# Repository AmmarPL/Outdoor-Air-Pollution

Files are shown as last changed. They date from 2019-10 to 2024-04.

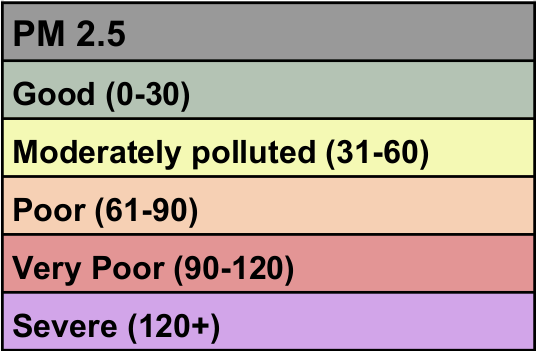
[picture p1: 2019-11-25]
Presentation/Inverse_Distance_Plots/Final/pm2.5.png

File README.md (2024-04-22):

# Embedded System for Air Quality Measurement

This project involves the design and implementation of an embedded system to measure air quality, with a focus on particulate matter (PM10) concentrations. It was specifically developed and tested during Diwali in 2019, when air pollution levels are known to spike significantly due to fireworks and other festivities.

# Overview
The air quality measurement device uses an ESP8266 microcontroller to gather data from various sensors and transmit it to a Python Flask server using oneM2M. The data is then visualized and analyzed through Thingspeak, showcasing significant spikes in PM10 levels, particularly around student residential areas. The entire circuit was designed using EagleCAD.

# Features
Sensor Integration: Incorporates multiple sensors to measure various pollutants, with a focus on PM10 particulate matter.

Connectivity: Uses an ESP8266 microcontroller for processing sensor data and providing Wi-Fi connectivity.


Data Handling: Transmits data to a Python Flask server, which is then pushed to Thingspeak for analysis and visualization.


EagleCAD Design: Custom PCB design for neatly organized and efficient sensor integration and microcontroller setup.


# Results
We found that some of the air quality indicators had a bad spike around Diwali.



We also found that these spikes were concentrated around the student residences. 



Both these plots are for PM10, but similar spikes were found in PM2.5 and CO, but not with NH3 and NO2.

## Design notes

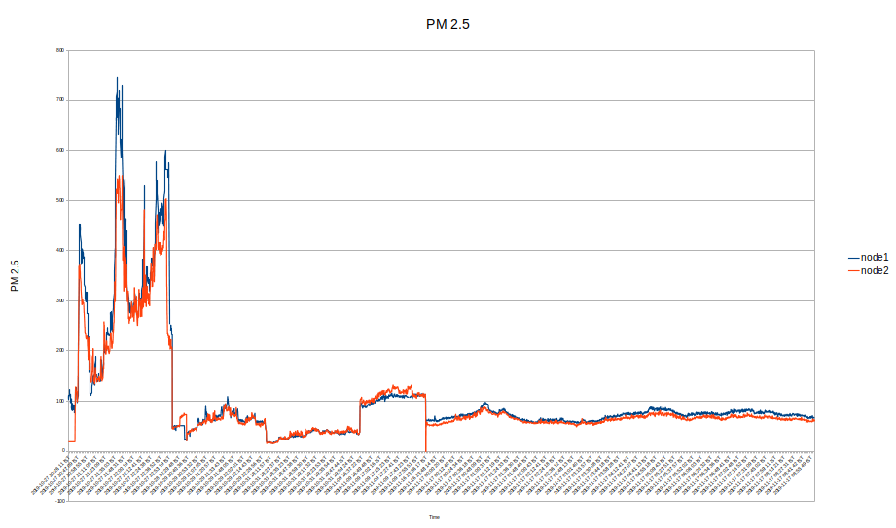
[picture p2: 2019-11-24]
Presentation/Node_Comparison/PM25_1_2.png

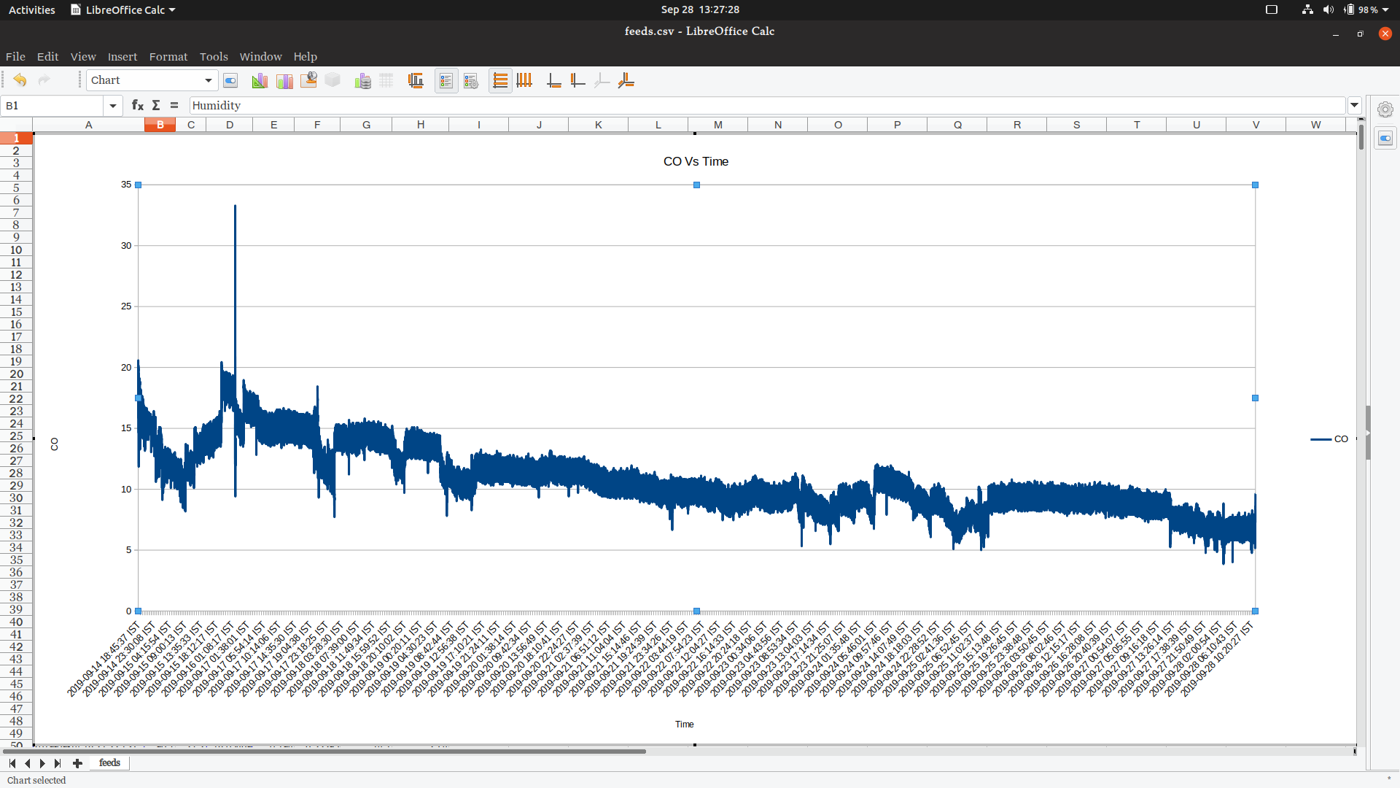
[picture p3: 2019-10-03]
Presentation/Team6_Plots/CO.png

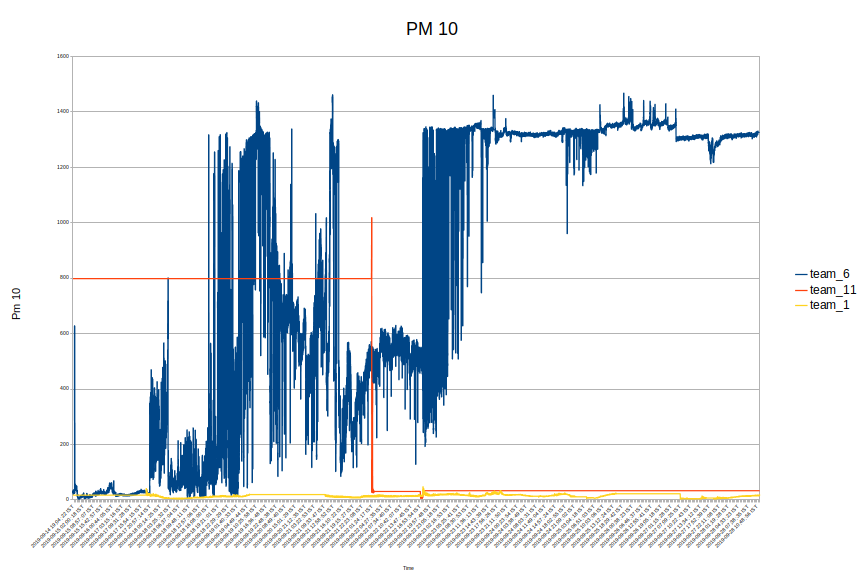
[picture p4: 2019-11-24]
Presentation/Comparison_Plots/Pm10.png

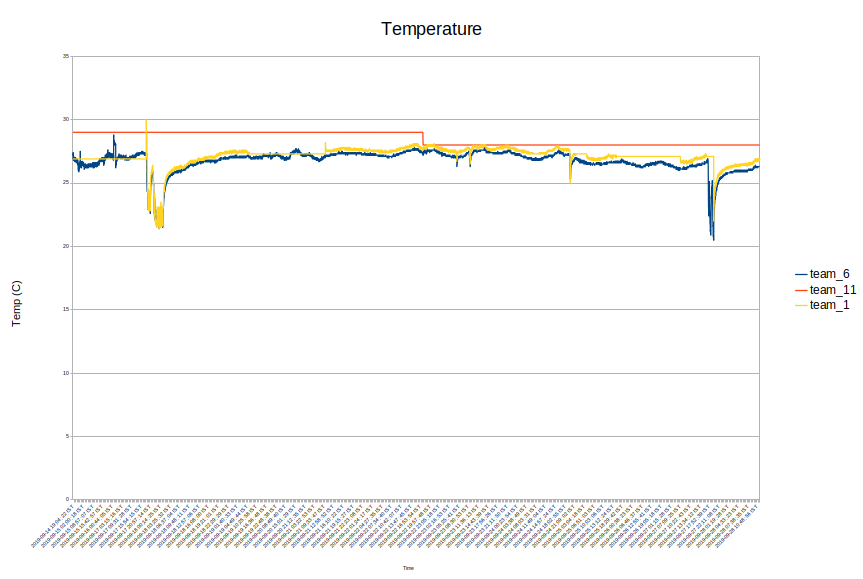
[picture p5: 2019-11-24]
Presentation/Comparison_Plots/Temperature.png

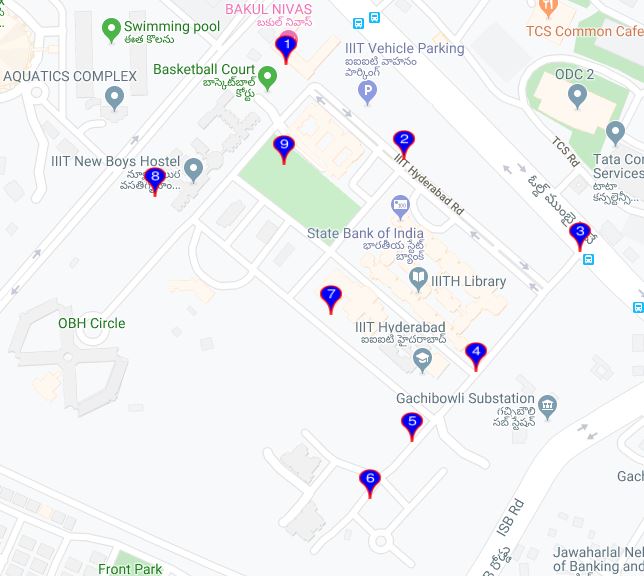
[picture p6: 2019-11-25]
Presentation/Locations/Map (2).JPG

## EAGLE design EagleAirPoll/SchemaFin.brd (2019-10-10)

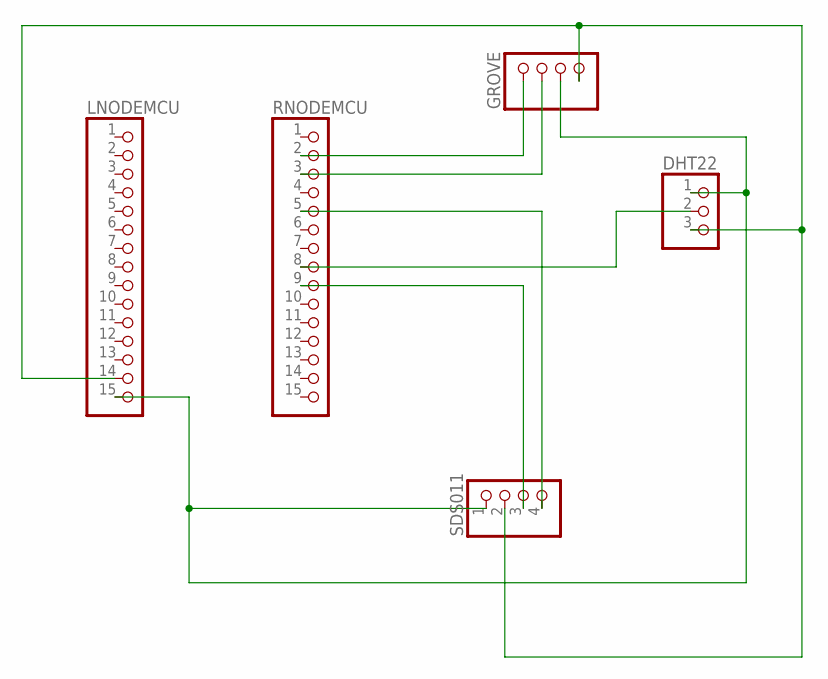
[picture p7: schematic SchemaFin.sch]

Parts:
DHT22: PINHD-1X3; 1X03
GROVE: PINHD-1X4M; 1X04M
LNODEMCU: PINHD-1X15; 1X15
RNODEMCU: PINHD-1X15; 1X15
SDS011: PINHD-1X4; 1X04

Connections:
unnamed: GROVE.1, RNODEMCU.2
unnamed: GROVE.2, RNODEMCU.3
unnamed: RNODEMCU.5, SDS011.4
unnamed: DHT22.2, RNODEMCU.8
unnamed: RNODEMCU.9, SDS011.3
unnamed: DHT22.1, GROVE.3, LNODEMCU.15, SDS011.1
unnamed: DHT22.3, GROVE.4, LNODEMCU.14, SDS011.2

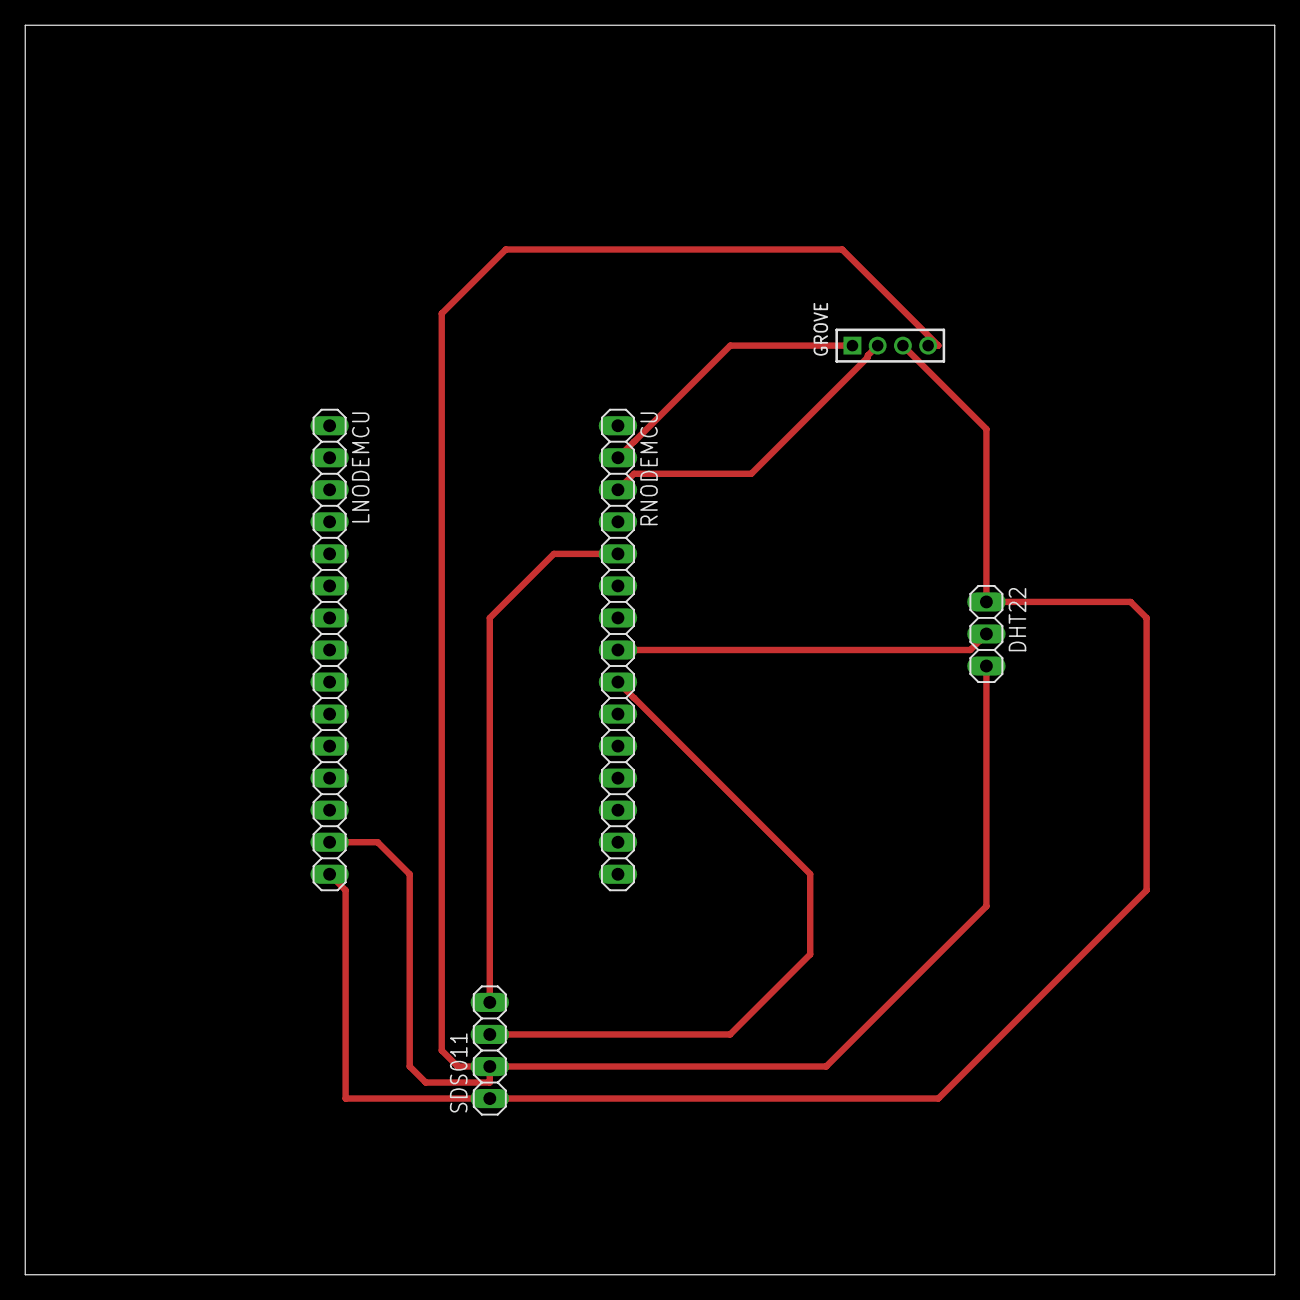
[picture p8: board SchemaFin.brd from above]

Board: 2 copper layers, 99.1 x 99.1 mm, 5 parts (0 on the bottom side), 7 nets.

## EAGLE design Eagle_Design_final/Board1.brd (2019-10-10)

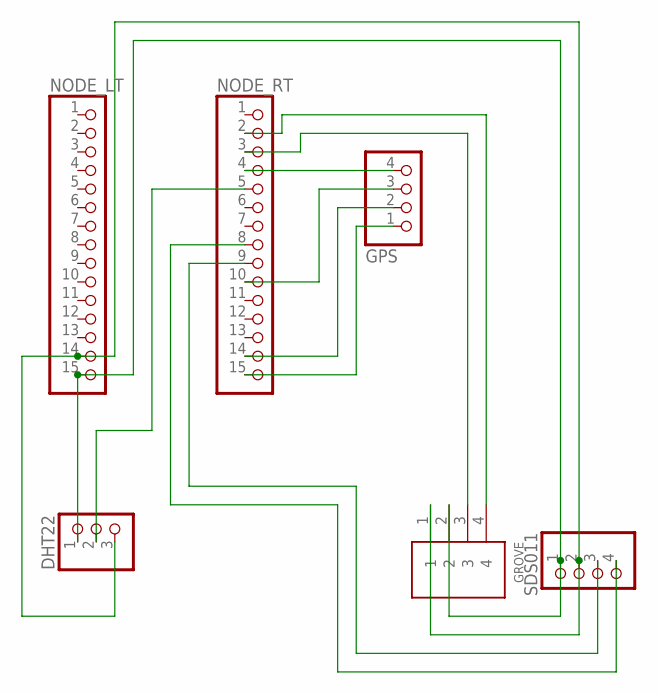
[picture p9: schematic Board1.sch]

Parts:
DHT22: PINHD-1X3; 1X03
GPS: PINHD-1X4; 1X04
GROVE: 4PIN; B4B-PH-K-S
NODE_LT: PINHD-1X15; 1X15
NODE_RT: PINHD-1X15; 1X15
SDS011: PINHD-1X4; 1X04

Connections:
unnamed: DHT22.1, GROVE.2, NODE_LT.15, SDS011.1
unnamed: DHT22.3, GROVE.1, NODE_LT.14, SDS011.2
unnamed: GPS.4, NODE_RT.4
unnamed: GPS.3, NODE_RT.10
unnamed: DHT22.2, NODE_RT.5
unnamed: NODE_RT.9, SDS011.3
unnamed: GPS.2, NODE_RT.14
unnamed: GROVE.3, NODE_RT.3
unnamed: GROVE.4, NODE_RT.2
unnamed: GPS.1, NODE_RT.15
unnamed: NODE_RT.8, SDS011.4

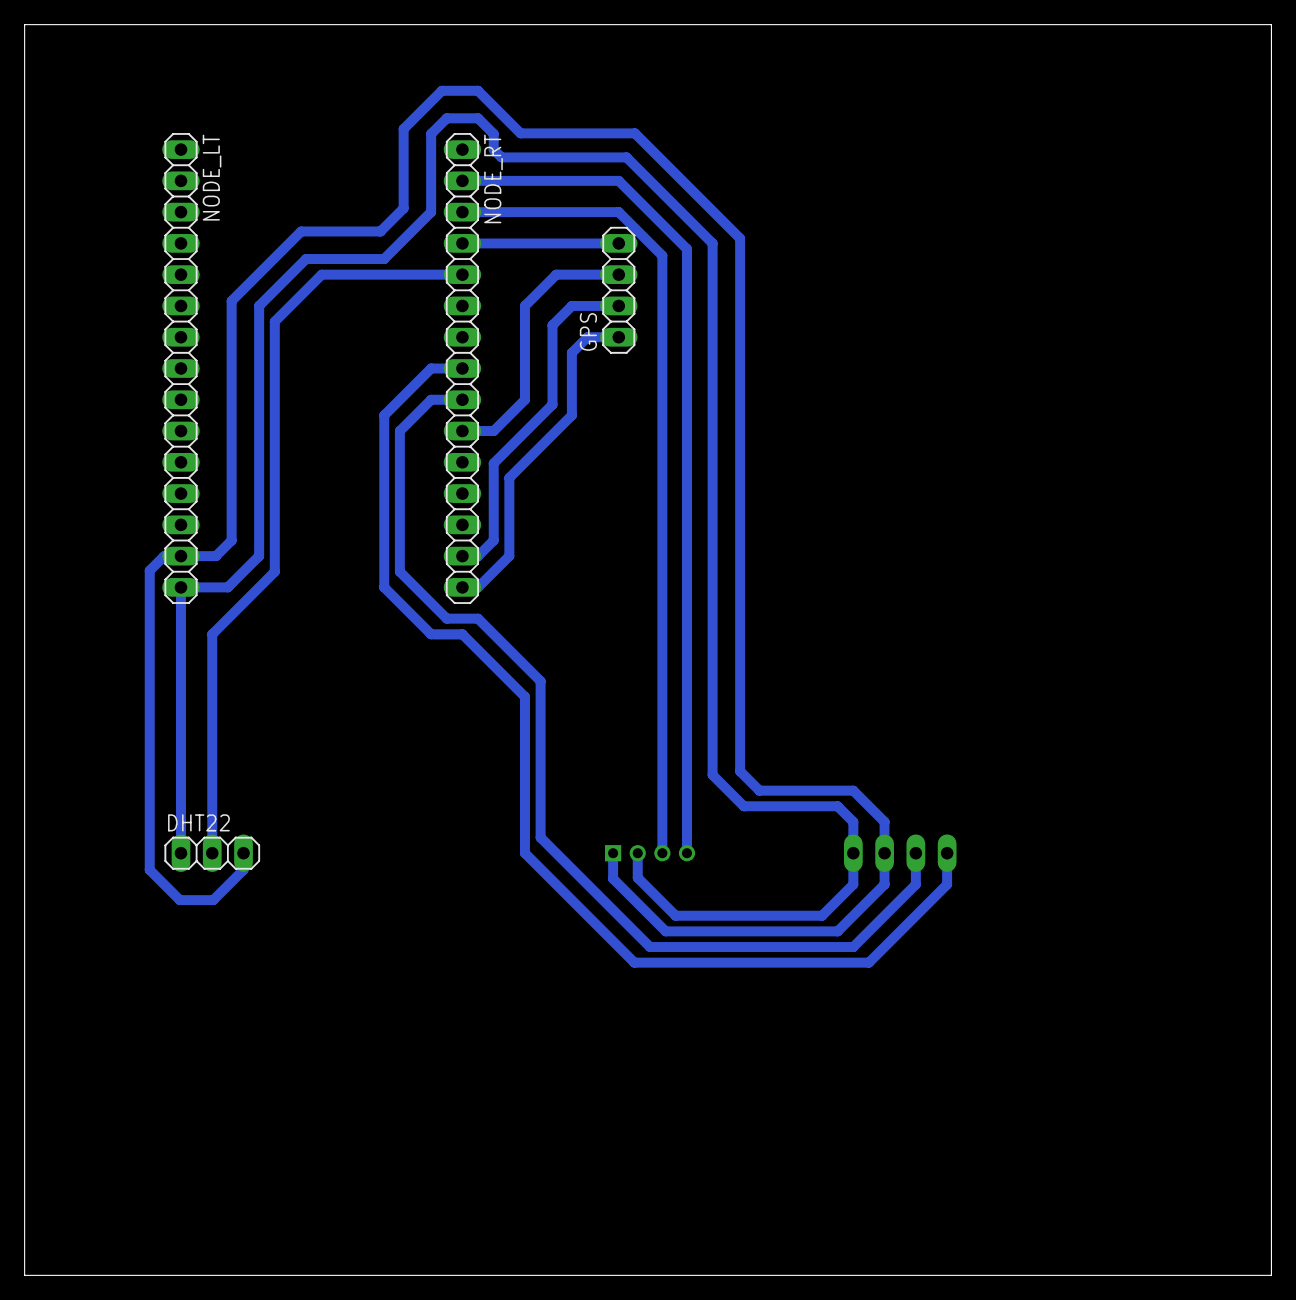
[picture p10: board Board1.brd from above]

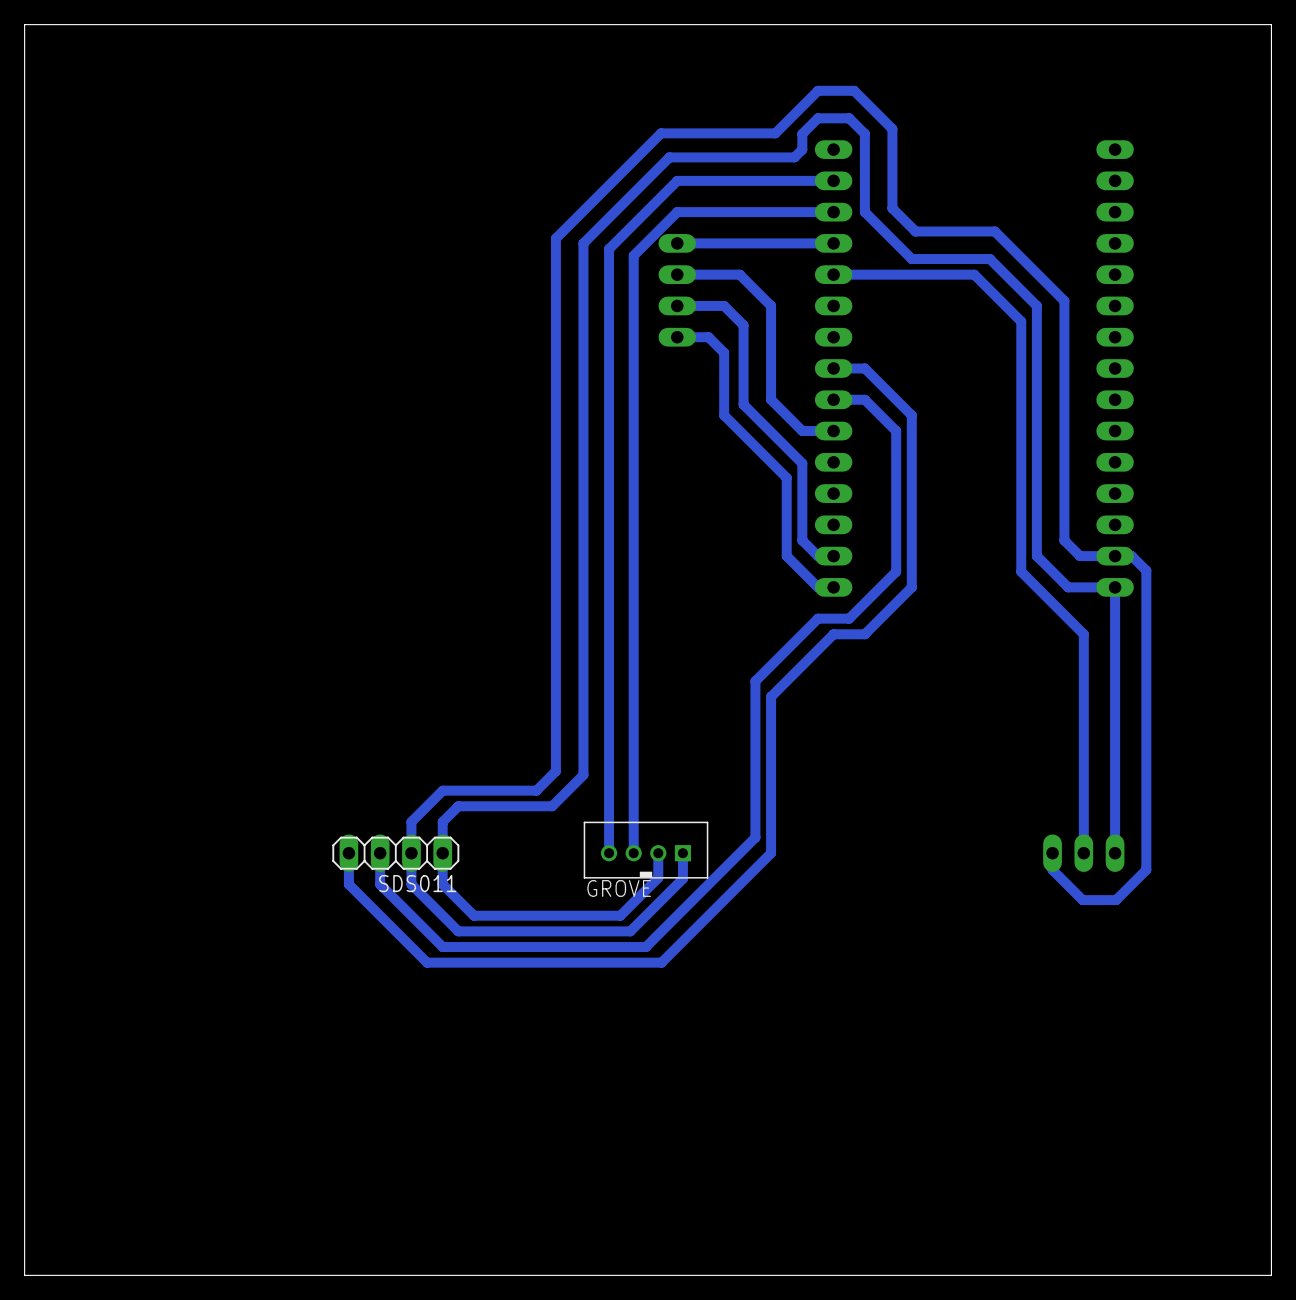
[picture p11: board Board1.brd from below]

Board: 2 copper layers, 101.3 x 101.6 mm, 6 parts (2 on the bottom side), 11 nets.

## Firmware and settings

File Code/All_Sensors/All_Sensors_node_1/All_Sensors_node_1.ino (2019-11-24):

//Libraries
#include <ThingSpeak.h>
#include "ESP8266WiFi.h"
#include "DHT.h"
#include <Wire.h>
#include "MutichannelGasSensor.h"
#include <SDS011.h>
#include <ESP8266HTTPClient.h>
#include <stdlib.h>
#include <SoftwareSerial.h>
#include <TinyGPS.h>


//Constants
#define DHTPIN D4    // what pin we're connected to
#define DHTTYPE DHT22   // DHT 22  (AM2302)
#define node_RX D5
#define node_TX D6
#define ADDR_I2C 0x04
#define LED D0
#define gps_RX D7
#define gps_TX D3
TinyGPS gps;
SoftwareSerial ss(gps_TX, gps_RX);
SDS011 my_sds;
DHT dht(DHTPIN, DHTTYPE); // Initialize DHT sensor for normal 16mhz Arduino
unsigned long Channel_ID = 864148;
char API_KEY[] = "UKQQPFB6U0R8V4US";
//char ssid[] = "JioFi_20E7D6C";
//char psswd[] = "2wufpbqmx0";
//char ssid[] = "esw-m19@iiith";
//char psswd[] = "e5W-eMai@3!20hOct";
//char ssid[] = "Nitro 5";
//char psswd[] = "wvZu69eF";
char ssid[] = "MGG5";
char psswd[] = "drowssapp";
WiFiClient  client;

//Variables
int chk, error;
float hum, temp, p10, p25, c, flat, flon;
String data;
unsigned long age;

//ONEM2M
int post(String ae, String container, String data) {
  String server = "http://onem2m.iiit.ac.in:80";
  String cse = "/~/in-cse/in-name/";
  char m2m[200];
  String Data;
  Data = "{\"m2m:cin\": {"
    "\"con\":\"" + data + "\""
    "}}";
  HTTPClient http;
  Serial.println("\nConnecting to : " + server+cse+ae+container);
  if(http.begin(server+cse+ae+container)) {
    http.addHeader("X-M2M-Origin", "admin:admin");
    http.addHeader("Content-type", "application/json;ty=4");
    Serial.println("Uploading data: " + data);
    int response = http.POST(Data);
    http.end();
    return response;
  }
  else {
    return 1;
  }
}

void update(int val) {
  if(val == 201) Serial.println("Data updated to OneM2M successfully\n");
  else Serial.println("There was an error while uploading Data to OneM2M. Error Code: " + String(val));
}

static void smartdelay(unsigned long ms) {
  unsigned long start = millis();
  do {
    while (ss.available())
      gps.encode(ss.read());
  } while (millis() - start < ms);
}

static void print_float(float val, float invalid, int len, int prec, int md) {
  char *temp;
  if (val == invalid) {
    while (len-- > 1){
      Serial.print('*');
      data = data + '*';
    }
    Serial.print(' ');
  }
  else{
    char temp[50];
    sprintf(temp, "%.6f", val);
    Serial.print(val, prec);
    data = data + String(temp);
    if(md == 0) ThingSpeak.setLatitude(String(temp));
    if(md == 1) ThingSpeak.setLongitude(String(temp));
    int vi = abs((int)val);
    int flen = prec + (val < 0.0 ? 2 : 1); // . and -
    flen += vi >= 1000 ? 4 : vi >= 100 ? 3 : vi >= 10 ? 2 : 1;
    for (int i=flen; i<len; ++i)
      Serial.print(' ');
  }
  data = data + ',';
  smartdelay(0);
}

static void print_date(TinyGPS &gps) {
  int year;
  byte month, day, hour, minute, second, hundredths;
  unsigned long age;
  gps.crack_datetime(&year, &month, &day, &hour, &minute, &second, &hundredths, &age);
  if (age == TinyGPS::GPS_INVALID_AGE) {
    Serial.print("********** ******** ");
    data = data + "********** ******** ";
  }
  else {
    char sz[32];
    sprintf(sz, "%02d/%02d/%02d %02d:%02d:%02d ",
        month, day, year, hour, minute, second);
    Serial.print(sz);
    data = data + sz;
  }
  smartdelay(0);
}

void setup(){
  pinMode(LED, OUTPUT);
  Serial.begin(115200);
  dht.begin();
  my_sds.begin(node_RX, node_TX);
  gas.begin(ADDR_I2C);
  gas.powerOn();  
  Serial.println("Begin.");
  Serial.println(WiFi.macAddress());
  WiFi.mode(WIFI_STA);
  WiFi.disconnect();
  ThingSpeak.begin(client);
  digitalWrite(LED, HIGH);
  ss.begin(9600);
  delay(10000);
}


void loop() {
     if(WiFi.status() != WL_CONNECTED){
      digitalWrite(LED, HIGH);
      Serial.print("Attempting to connect to SSID: ");
      Serial.print(ssid); 
      Serial.println(" with password: " + String(psswd));
      while(WiFi.status() != WL_CONNECTED){
        WiFi.begin(ssid, psswd);  // Connect to WPA/WPA2 network. Change this line if using open or WEP network
        Serial.print(".");
        delay(5000);     
      } 
      Serial.println("\nConnected.");
      digitalWrite(LED, LOW);
    }

    
    hum = dht.readHumidity();
    temp= dht.readTemperature();

//    Print temp and humidity values to serial monitor
    Serial.print("Humidity: ");
    Serial.print(hum);
    Serial.print(" %, Temp: ");
    Serial.print(temp);
    Serial.println(" Celsius");
    ThingSpeak.setField(1, hum);
    ThingSpeak.setField(2, temp);
    data = String(temp) + "," + String(hum) + ',';

    
    error = my_sds.read(&p25, &p10);
    if (!error) {
      Serial.println("P2.5: " + String(p25) + "\t" + "P10:  " + String(p10));
      ThingSpeak.setField(6, p25);
      ThingSpeak.setField(7, p10);
      data = data + String(p25) + "," + String(p10) + ',';
      
    }
    else {
      data = data + "-1,-1,";
    }
//

    c = gas.measure_CO();
    Serial.print("The concentration of CO is ");
    if(c>=0) Serial.print(c);
    else Serial.print("invalid");
    Serial.println(" ppm");
    ThingSpeak.setField(3, c);
    data = data + String(c) + ",";
    
    c = gas.measure_NO2();
    Serial.print("The concentration of NO2 is ");
    if(c>=0) Serial.print(c);
    else Serial.print("invalid");
    Serial.println(" ppm");
    ThingSpeak.setField(4, c);
    data = data + String(c) + ",";

    c = gas.measure_NH3();
    Serial.print("The concentration of NH3 is ");
    if(c>=0) Serial.print(c);
    else Serial.print("invalid");
    Serial.println(" ppm");
    ThingSpeak.setField(5, c);
    data = data + String(c) + ',';


    gps.f_get_position(&flat, &flon, &age);
    print_float(flat, TinyGPS::GPS_INVALID_F_ANGLE, 10, 6, 0);
    print_float(flon, TinyGPS::GPS_INVALID_F_ANGLE, 11, 6, 1);
    Serial.println();
    print_date(gps);
    smartdelay(1000);
    data = data + ",OAP4_1";
    
    update(post("Team6_Outdoor_air_pollution_mobile/", "node_1", data));

    int response;
    if((response = ThingSpeak.writeFields(Channel_ID, API_KEY)) == 200) {
      Serial.println("Data Updated to ThingSpeak successfully!");
      }
    else {
      Serial.println("Problem Updating data for ThingSpeak!\nError code: " + String(response)); 
    }
    delay(15000); //Delay 15 sec.
    Serial.println("...\n\n\n\n\n\n\n");
}

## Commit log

2019-10-07 Put Eagle files in the folder
    [SchemaFin.brd, SchemaFin.sch]
2019-10-07 Remove consistency errors
    [SchemaFin.brd, SchemaFin.sch]
2019-10-07 Modify Board
    [SchemaFin.brd, SchemaFin.sch]
2019-10-10 Updated Final Code, Added Final Eagle Board Schematics, Added OneM2M code
    [Board1.brd, Board1.sch]
2019-11-24 Added most things
    [Location values.csv]
2019-11-24 All commit
    [1.csv, 11.csv, 2.csv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]
